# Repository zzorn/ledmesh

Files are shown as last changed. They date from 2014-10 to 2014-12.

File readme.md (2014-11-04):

Ledmesh
=======

Overview
--------

Mesh networked nodes controlling LED light strips, LED spotlights, sensors, and other things.

The network uses wireless radio modules to communicate between nodes.

Ledmesh can be used to create coherent led lighting effects in a space (e.g. light waves flowing around walls), 
as well as for controlling 12V lighting (e.g. led spotlights).

Ledmesh can also be used as an information radiator, connecting some nodes up to computers or suitable sensors, 
and sending out light waves to nearby nodes or doing light effect changes for the whole network on different events.

Ledmesh needs configuration after installation, to tell nodes their relative locations, sensors to use for activating different modes or sending waves, and so on.

Effects
-------

The main type of effect consist of nodes sending waves of light and color along light strips towards neighboring nodes, where the waves can carry on to other nodes.
Waves can have various intensity, hue/sat/lum (also negative), wavelength, travel distance/time, random noise, color gradients, and so on.  Multiple waves can travel along a strip in various directions
at the same time, the different waves are blended together.

Waves could leave the leds at zero after they pass, or they could leave them at some other intensity, which will be changed by the next wave.  (Or the base intensity might be based on the mode(s) the node is in?)

Waves can be used to create a lot of different effects (even global fade ins or outs).  If there are some ideas for effect types that are not possible to do with waves, those might be added later.

Single outputs, like led spotlights, could be treated like a led strip of length one (or some other length, if the spotlights are arranged in a row).

Node States
-----------

Nodes can have various states depending on their sensor readings and global or remote sensor readings received with communication from other nodes.
The state(s) a node is in determines what kind of effects it generates to attached led strips and other outputs.

A node need not be either in a state or not, it can also be partially in a state (e.g. a potentiometer could be used to place a node partially in a 'lit' state).

The degree a state is activated depends either directly or indirectly on one or more sensor inputs, with some multipliers.

Different states can also have different speeds or required activation that they activate or deactivate with (a kind of inertia), to provide some hysteresis and reduce quick flickering between states.

For more complicated behaviour, the activation degree of states in the current or neighboring nodes could be used as a sensor value to help determine the activation of a node (creating a neuron-like setup).

Modes
-----

Sometimes the general apperance of the whole network should be changed.  This could be done with a mode concept, where a mode enables states contained in it, and disables states contained within any previously active mode.
Some states might be independent of the mode.

One possibility is to allow multiple modes as once, although that might be more complications than necessary.

Modes could maybe change depending on signals (which would indicate some hierarchial state system might be better than a separate mode concept).

For example, during the evening a more orange toned lighting mode could be activated, there could be modes for work that needs a lot of light, for more muted lighting for general hanging around,
for some darker and slower night illumination, a party mode, and a few different looking general light modes.

Node types
----------

There are two different types of nodes:

* Led Node
  * Controls zero or more LED strips, LED lights, etc.  Also has two extra I/O pins.
  * Has locations for sensor modules such as PIR (motion detector) and sound.
  * Has builtin light level sensor.
  * Has location for a radio communication module.

* Remote Controller
  * Contains a character LCD screen and turn wheels (and possibly a color / color gradient preview LED) for configuring the network.  It allows:
     * Configuring the length of led strips connected to different nodes (needs to be done once after installation).  
     * Defining fixed signals for different nodes (e.g. height above floor, or x/y coordinate), which can be used in effects.
     * Defining the signals that different inputs on different nodes affect, and whether the signals are global or local to the node.
       Some inputs are pre-configured (e.g. light level sensors, etc), while others could be custom (e.g. door open microswitch, red alert/instant party button, etc).
     * Defining gradients.
     * Defining various named wave types.
     * Defining various wave generators (?).
     * Defining various node states
        * Connecting wave generators to the node state
        * Specifying the activation or deactivation effects of different signals (and state activations) from this node or neighboring nodes or global signals on this state.
        * Default lifetime of this state
        * Slowness / quickness of state change = change inertia
        * Whether this state should be available on all nodes, or only a selected subset (always non-active on other nodes)  [Is this needed?  Maybe not]
     * The default screen allows setting various selected global signals, and selecting the current mode(s).
  * Could also have a USB connection to computer, and some serial based protocol to provide updates to signal states, as well as communicate states from the Ledmess network.  The protocol could also contain commands for configuring LedMesh.
  * Might also contain support for bluetooth control (for control from android app)
  * Might support an ethernet connector as well.

Control and configuration application
-------------------------------------

To be written in Java, as that allows easy porting to both android and PC.

The software on the remote controller will probably be more limited, but it would be nice to be able to do all configuration from it if needed.

Builtin Signals
---------------

* Time of day
* Age of this state (0 = newborn, 100% = at the lifetime of the state).

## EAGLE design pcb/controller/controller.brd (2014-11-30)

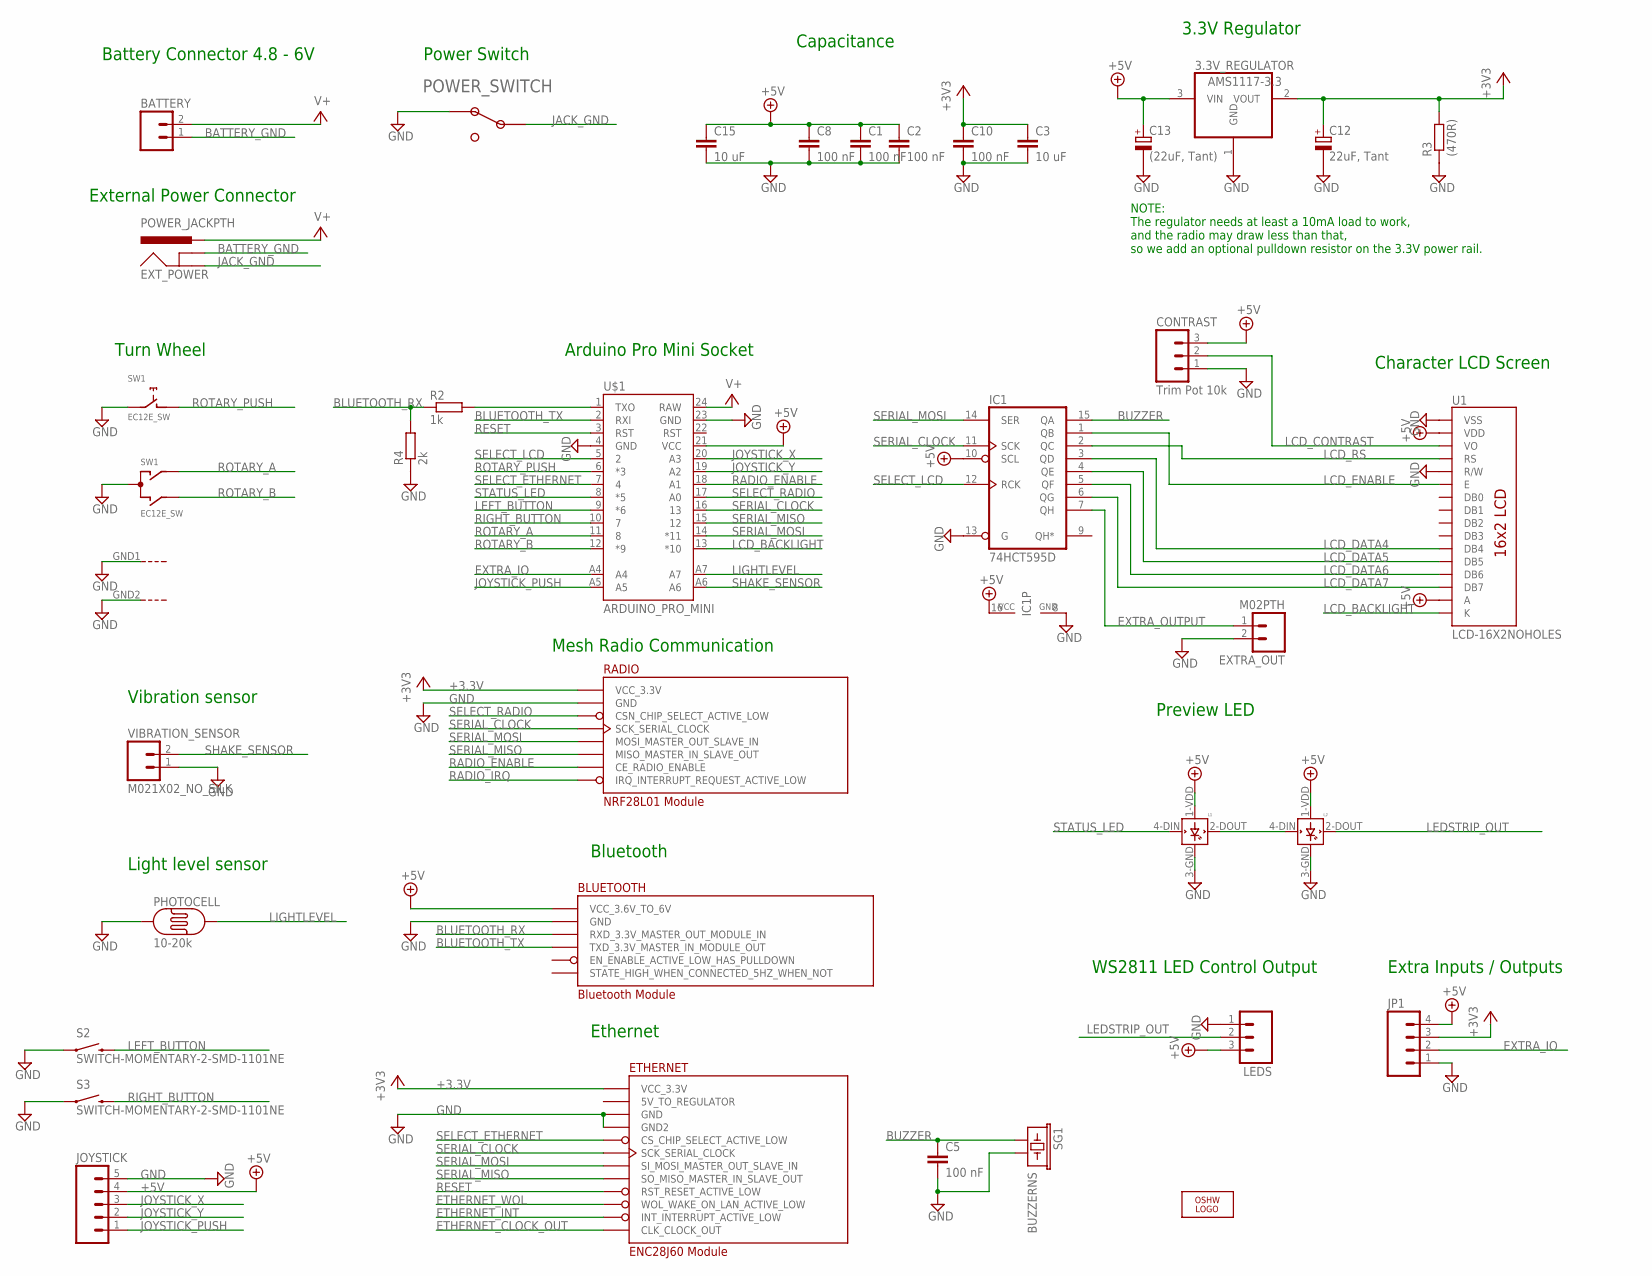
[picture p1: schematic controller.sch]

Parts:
3.3V_REGULATOR: AMS1117-3.3; SOT223
BATTERY: M02LOCK_LONGPADS; 1X02_LOCK_LONGPADS
BLUETOOTH: Bluetooth Module; BLUETOOTH_MODULE
C1, C2, C5, C8, C10: 100 nF; C0805
C3, C15: 10 uF; C0805K
C12: 22uF, Tant; SMC_A
C13: (22uF, Tant); SMC_A
CONTRAST: Trim Pot 10k; 1X03_NO_SILK
ETHERNET: ENC28J60 Module; ETHERNET_ENC28J60_MODULE
EXTRA_OUT: M02PTH; 1X02
EXT_POWER: POWER_JACKPTH; POWER_JACK_PTH
IC1: 74HCT595D; SO16
JOYSTICK: M05NO_SILK; 1X05_NO_SILK
JP1: M041X04_NO_SILK; 1X04_NO_SILK
L1, L2: WS2812B
LEDS: M03PTH; 1X03
LOGO3: LOGO-OSHW-8MILX0100-NT; OSHW_8X100_NOTEXT
PHOTOCELL: 10-20k; PHOTOCELL
POWER_SWITCH: KNC1-101-2P
R2: 1k; M0805
R3: (470R); M0805
R4: 2k; M0805
RADIO: NRF28L01 Module; NRF24L01_MODULE
S2, S3: SWITCH-MOMENTARY-2-SMD-1101NE; TACTILE-SWITCH-1101NE
SG1: BUZZERNS; BUZZER-12MM-NS
SW1: EC12E_SW; ALPS_EC12E_SW
U1: LCD-16X2NOHOLES; LCD-16X2_NOHOLES
U$1: ARDUINO_PRO_MINI
VIBRATION_SENSOR: M021X02_NO_SILK; 1X02_NO_SILK

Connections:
+3.3V: 3.3V_REGULATOR.2 (VOUT), C3.1, C10.1, C12.+, ETHERNET.P$2 (VCC_3.3V), JP1.3, R3.2, RADIO.P$2 (VCC_3.3V)
+5V: 3.3V_REGULATOR.3 (VIN), BLUETOOTH.P$5 (VCC_3.6V_TO_6V), C1.1, C2.1, C8.1, C13.+, C15.1, CONTRAST.3, IC1.10 (SCL), IC1.16 (VCC), JOYSTICK.4, JP1.4, L1.1-VDD (VDD), L2.1-VDD (VDD), LEDS.3, U1.2 (VDD), U1.15 (A), U$1.21 (VCC)
BATTERY_GND: BATTERY.1, EXT_POWER.GNDBREAK
BLUETOOTH_RX: BLUETOOTH.P$2 (RXD_3.3V_MASTER_OUT_MODULE_IN), R2.1, R4.2
BLUETOOTH_TX: BLUETOOTH.P$3 (TXD_3.3V_MASTER_IN_MODULE_OUT), U$1.2 (RXI)
BUZZER: C5.1, IC1.15 (QA), SG1.+ (1)
ETHERNET_CLOCK_OUT: ETHERNET.P$9 (CLK_CLOCK_OUT)
ETHERNET_INT: ETHERNET.P$10 (INT_INTERRUPT_ACTIVE_LOW)
ETHERNET_WOL: ETHERNET.P$7 (WOL_WAKE_ON_LAN_ACTIVE_LOW)
EXTRA_IO: JP1.2, U$1.A4
EXTRA_OUTPUT: EXTRA_OUT.1, IC1.7 (QH)
GND: 3.3V_REGULATOR.1 (GND), BLUETOOTH.P$4 (GND), C1.2, C2.2, C3.2, C5.2, C8.2, C10.2, C12.-, C13.-, C15.2, CONTRAST.1, ETHERNET.P$1 (GND), ETHERNET.P$11 (GND2), EXTRA_OUT.2, IC1.8 (GND), IC1.13 (G), JOYSTICK.5, JP1.1, L1.3-GND (GND), L2.3-GND (GND), LEDS.1, PHOTOCELL.1, POWER_SWITCH.P$1, R3.1, R4.1, RADIO.P$1 (GND), S2.P$1 (1), S3.P$1 (1), SG1.- (2), SW1.C, SW1.E (2), SW1.GND1 (G), SW1.GND2 (G), U1.1 (VSS), U1.5 (R/W), U$1.4 (GND), U$1.23 (GND), VIBRATION_SENSOR.1
JACK_GND: EXT_POWER.GND, POWER_SWITCH.P$2
JOYSTICK_PUSH: JOYSTICK.1, U$1.A5
JOYSTICK_X: JOYSTICK.3, U$1.20 (A3)
JOYSTICK_Y: JOYSTICK.2, U$1.19 (A2)
LCD_BACKLIGHT: U1.16 (K), U$1.13 (*10)
LCD_CONTRAST: CONTRAST.2, U1.3 (VO)
LCD_DATA4: IC1.3 (QD), U1.11 (DB4)
LCD_DATA5: IC1.4 (QE), U1.12 (DB5)
LCD_DATA6: IC1.5 (QF), U1.13 (DB6)
LCD_DATA7: IC1.6 (QG), U1.14 (DB7)
LCD_ENABLE: IC1.1 (QB), U1.6 (E)
LCD_RS: IC1.2 (QC), U1.4 (RS)
LEDSTRIP_OUT: L2.2-DOUT (DOUT), LEDS.2
LEFT_BUTTON: S2.P$2 (2), U$1.9 (*6)
LIGHTLEVEL: PHOTOCELL.2, U$1.A7
unnamed: R2.2, U$1.1 (TXO)
RADIO_ENABLE: RADIO.P$3 (CE_RADIO_ENABLE), U$1.18 (A1)
RADIO_IRQ: RADIO.P$8 (IRQ_INTERRUPT_REQUEST_ACTIVE_LOW)
RESET: ETHERNET.P$4 (RST_RESET_ACTIVE_LOW), U$1.3 (RST)
RIGHT_BUTTON: S3.P$2 (2), U$1.10 (7)
ROTARY_A: SW1.A, U$1.11 (8)
ROTARY_B: SW1.B, U$1.12 (*9)
ROTARY_PUSH: SW1.D (1), U$1.6 (*3)
SELECT_ETHERNET: ETHERNET.P$3 (CS_CHIP_SELECT_ACTIVE_LOW), U$1.7 (4)
SELECT_LCD: IC1.12 (RCK), U$1.5 (2)
SELECT_RADIO: RADIO.P$4 (CSN_CHIP_SELECT_ACTIVE_LOW), U$1.17 (A0)
SERIAL_CLOCK: ETHERNET.P$6 (SCK_SERIAL_CLOCK), IC1.11 (SCK), RADIO.P$5 (SCK_SERIAL_CLOCK), U$1.16 (13)
SERIAL_MISO: ETHERNET.P$8 (SO_MISO_MASTER_IN_SLAVE_OUT), RADIO.P$7 (MISO_MASTER_IN_SLAVE_OUT), U$1.15 (12)
SERIAL_MOSI: ETHERNET.P$5 (SI_MOSI_MASTER_OUT_SLAVE_IN), IC1.14 (SER), RADIO.P$6 (MOSI_MASTER_OUT_SLAVE_IN), U$1.14 (*11)
SHAKE_SENSOR: U$1.A6, VIBRATION_SENSOR.2
STATUS_LED: L1.4-DIN (DIN), U$1.8 (*5)
STATUS_LED2: L1.2-DOUT (DOUT), L2.4-DIN (DIN)
V+: BATTERY.2, EXT_POWER.PWR, U$1.24 (RAW)

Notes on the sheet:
Arduino Pro Mini Socket
Capacitance
Light level sensor
Extra Inputs / Outputs
Battery Connector 4.8 - 6V
Mesh Radio Communication
3.3V Regulator
NOTE: The regulator needs at least a 10mA load to work, and the radio may draw less than that, so we add an optional pulldown resistor on the 3.3V power rail.
Preview LED
Vibration sensor
Turn Wheel
Character LCD Screen
WS2811 LED Control Output
Bluetooth
Ethernet
External Power Connector
Power Switch

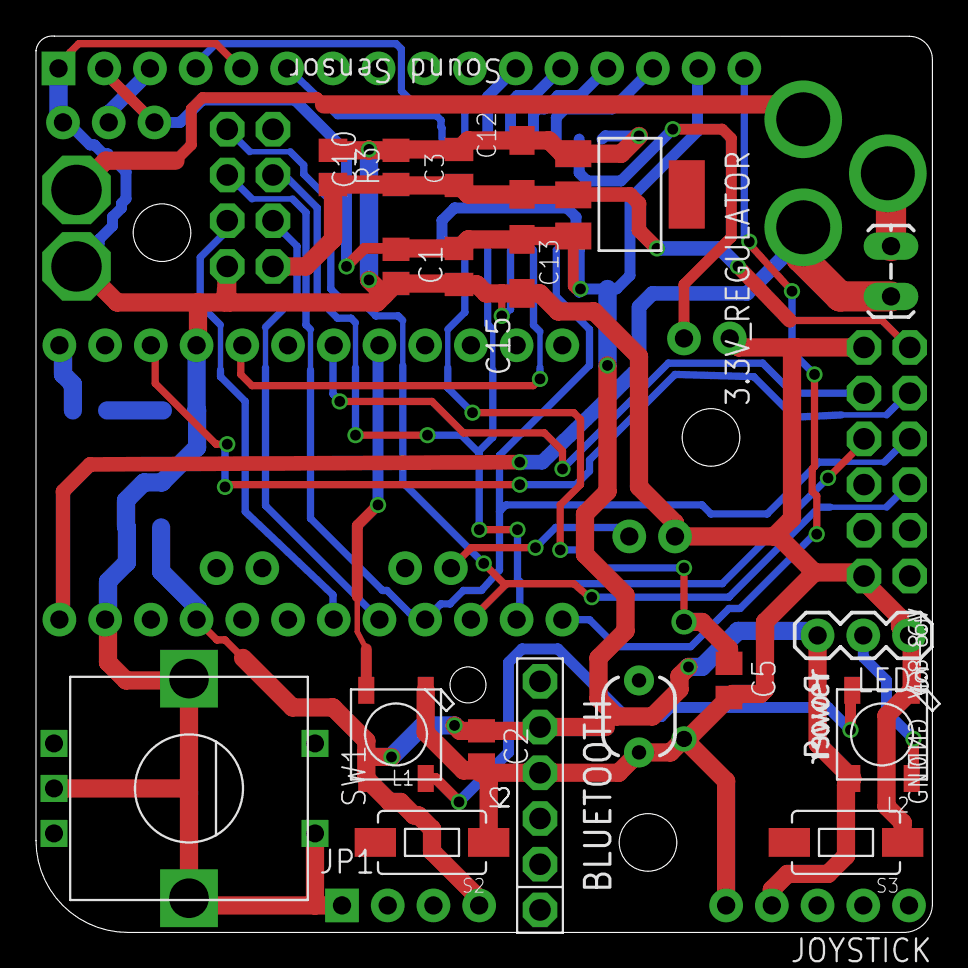
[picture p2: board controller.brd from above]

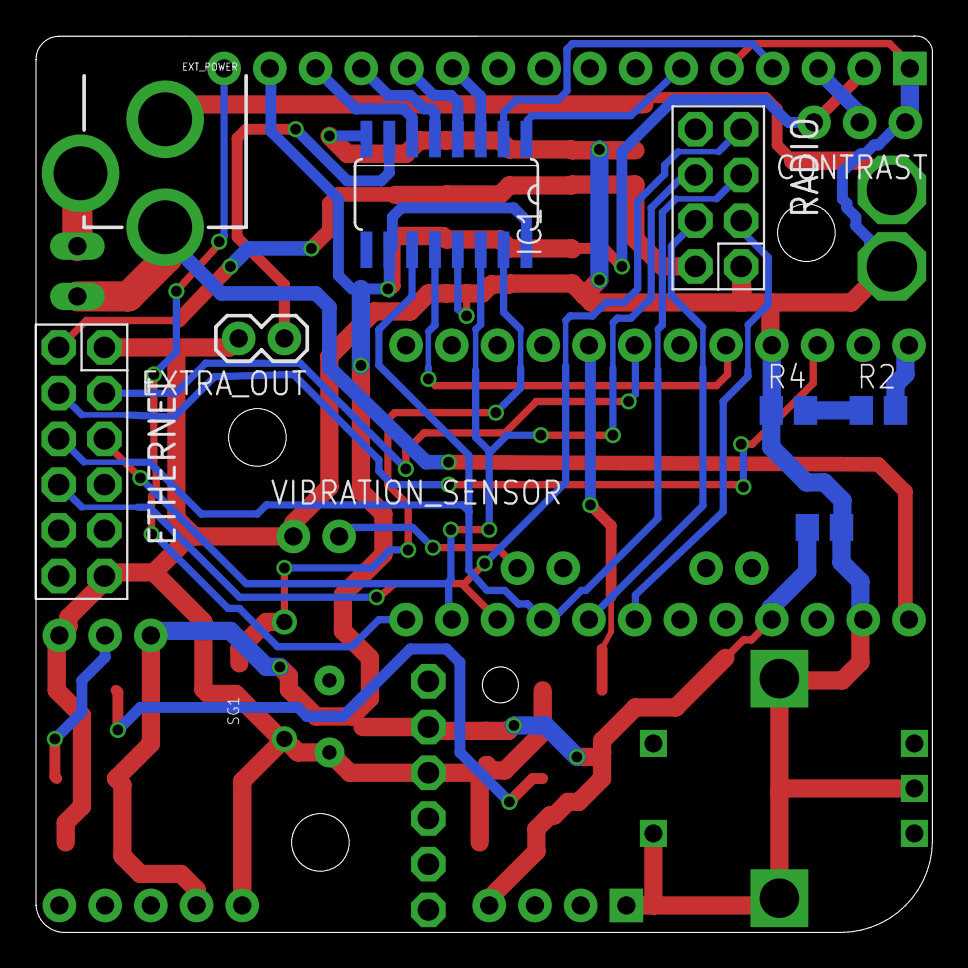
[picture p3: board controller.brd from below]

Board: 2 copper layers, 49.8 x 49.8 mm, 36 parts (12 on the bottom side), 41 nets.

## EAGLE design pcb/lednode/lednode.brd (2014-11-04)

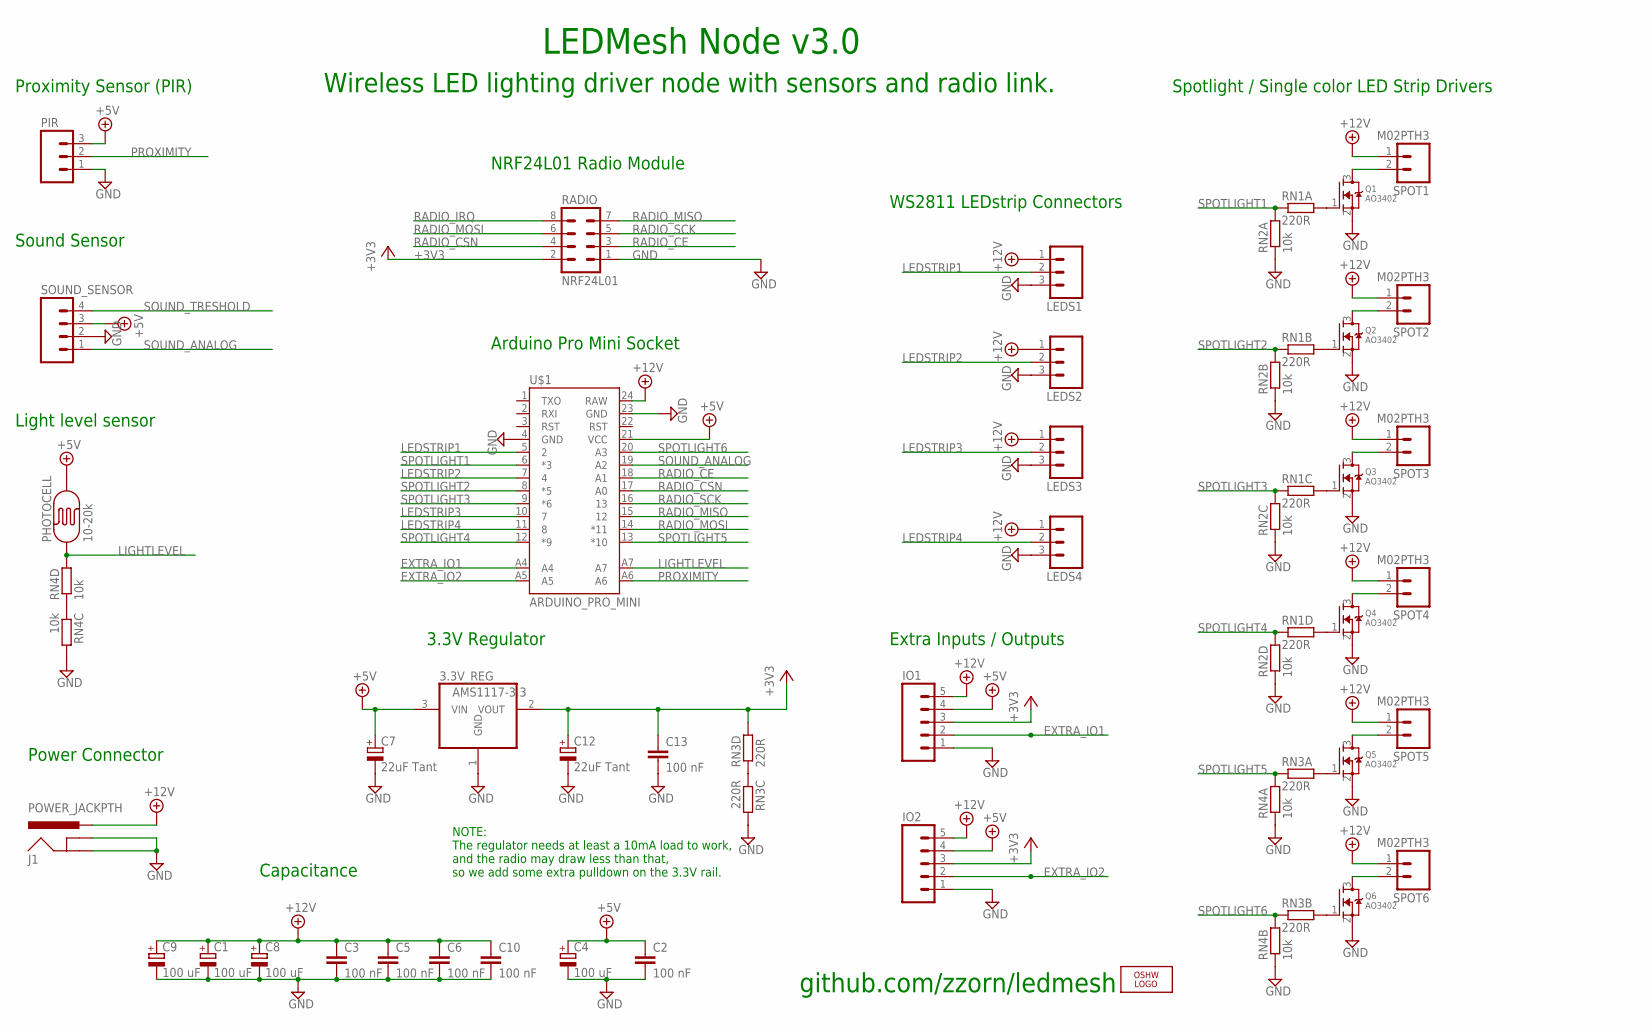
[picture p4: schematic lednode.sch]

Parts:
3.3V_REG: AMS1117-3.3; SOT223
C1, C4, C8, C9: 100 uF; E2,5-6
C2, C3, C5, C6, C10, C13: 100 nF; C0805
C7, C12: 22uF Tant; SMC_A
IO1, IO2: M05PTH; 1X05
J1: POWER_JACKPTH; POWER_JACK_PTH
LEDS1, LEDS2, LEDS3, LEDS4: M03LONGPADS; 1X03_LONGPADS
LOGO3: LOGO-OSHW-8MILX0100-NT; OSHW_8X100_NOTEXT
PHOTOCELL: 10-20k; PHOTOCELL
PIR: M03PTH; 1X03
Q1, Q2, Q3, Q4, Q5, Q6: AO3402; SOT23-W
RADIO: NRF24L01; MA04-2
RN1, RN3: 220R; RN8P-4R-CRA06S
RN2, RN4: 10k; RN8P-4R-CRA06S
SOUND_SENSOR: M041X04_NO_SILK; 1X04_NO_SILK
SPOT1, SPOT2, SPOT3, SPOT4, SPOT5, SPOT6: M02PTH3; 1X02_LONGPADS
U$1: ARDUINO_PRO_MINI

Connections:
+3V3: 3.3V_REG.2 (VOUT), C12.+, C13.1, IO1.3, IO2.3, RADIO.2, RN3.5 (2)
+5V: 3.3V_REG.3 (VIN), C2.1, C4.+, C7.+, IO1.4, IO2.4, PHOTOCELL.2, PIR.3, SOUND_SENSOR.3, U$1.21 (VCC)
+12V: C1.+, C3.1, C5.1, C6.1, C8.+, C9.+, C10.1, IO1.5, IO2.5, J1.PWR, LEDS1.1, LEDS2.1, LEDS3.1, LEDS4.1, SPOT1.1, SPOT2.1, SPOT3.1, SPOT4.1, SPOT5.1, SPOT6.1, U$1.24 (RAW)
EXTRA_IO1: IO1.2, U$1.A4
EXTRA_IO2: IO2.2, U$1.A5
GND: 3.3V_REG.1 (GND), C1.-, C2.2, C3.2, C4.-, C5.2, C6.2, C7.-, C8.-, C9.-, C10.2, C12.-, C13.2, IO1.1, IO2.1, J1.GND, J1.GNDBREAK, LEDS1.3, LEDS2.3, LEDS3.3, LEDS4.3, PIR.1, Q1.2 (S), Q2.2 (S), Q3.2 (S), Q4.2 (S), Q5.2 (S), Q6.2 (S), RADIO.1, RN2.1, RN2.2 (1), RN2.3 (1), RN2.4 (1), RN3.6 (2), RN4.1, RN4.2 (1), RN4.6 (2), SOUND_SENSOR.2, U$1.4 (GND), U$1.23 (GND)
LEDSTRIP1: LEDS1.2, U$1.5 (2)
LEDSTRIP2: LEDS2.2, U$1.7 (4)
LEDSTRIP3: LEDS3.2, U$1.10 (7)
LEDSTRIP4: LEDS4.2, U$1.11 (8)
LIGHTLEVEL: PHOTOCELL.1, RN4.5 (2), U$1.A7
unnamed: Q5.3 (D), SPOT5.2
unnamed: Q1.3 (D), SPOT1.2
unnamed: Q2.3 (D), SPOT2.2
unnamed: Q4.3 (D), SPOT4.2
unnamed: Q3.3 (D), SPOT3.2
unnamed: Q1.1 (G), RN1.8 (2)
unnamed: Q2.1 (G), RN1.7 (2)
unnamed: Q4.1 (G), RN1.5 (2)
unnamed: Q3.1 (G), RN1.6 (2)
unnamed: Q5.1 (G), RN3.8 (2)
unnamed: Q6.3 (D), SPOT6.2
unnamed: RN4.3 (1), RN4.4 (1)
unnamed: Q6.1 (G), RN3.7 (2)
unnamed: RN3.3 (1), RN3.4 (1)
PROXIMITY: PIR.2, U$1.A6
RADIO_CE: RADIO.3, U$1.18 (A1)
RADIO_CSN: RADIO.4, U$1.17 (A0)
RADIO_IRQ: RADIO.8
RADIO_MISO: RADIO.7, U$1.15 (12)
RADIO_MOSI: RADIO.6, U$1.14 (*11)
RADIO_SCK: RADIO.5, U$1.16 (13)
SOUND_ANALOG: SOUND_SENSOR.1, U$1.19 (A2)
SOUND_TRESHOLD: SOUND_SENSOR.4
SPOTLIGHT1: RN1.1, RN2.8 (2), U$1.6 (*3)
SPOTLIGHT2: RN1.2 (1), RN2.7 (2), U$1.8 (*5)
SPOTLIGHT3: RN1.3 (1), RN2.6 (2), U$1.9 (*6)
SPOTLIGHT4: RN1.4 (1), RN2.5 (2), U$1.12 (*9)
SPOTLIGHT5: RN3.1, RN4.8 (2), U$1.13 (*10)
SPOTLIGHT6: RN3.2 (1), RN4.7 (2), U$1.20 (A3)

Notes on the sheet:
Arduino Pro Mini Socket
Capacitance
WS2811 LEDstrip Connectors
Light level sensor
Proximity Sensor (PIR)
Extra Inputs / Outputs
Power Connector
Spotlight / Single color LED Strip Drivers
Sound Sensor
NRF24L01 Radio Module
3.3V Regulator
NOTE: The regulator needs at least a 10mA load to work, and the radio may draw less than that, so we add some extra pulldown on the 3.3V rail.
LEDMesh Node v3.0
Wireless LED lighting driver node with sensors and radio link.
github.com/zzorn/ledmesh

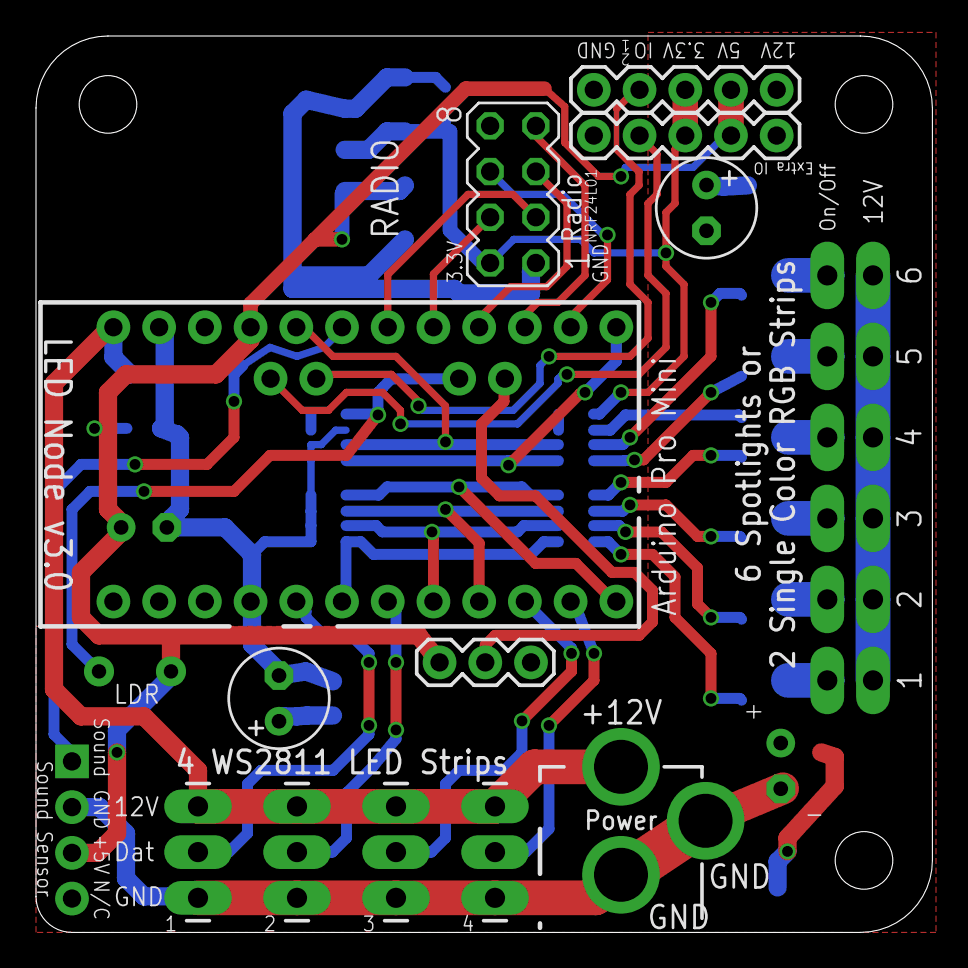
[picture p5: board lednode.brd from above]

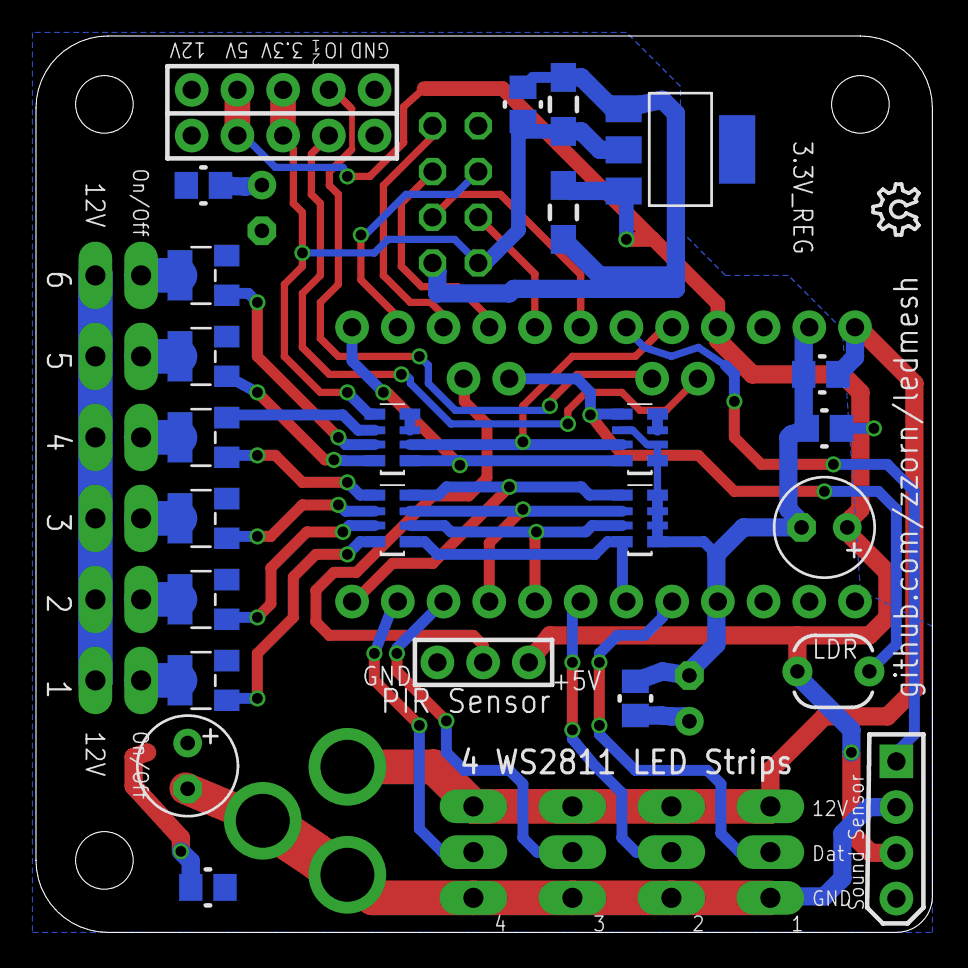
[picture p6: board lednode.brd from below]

Board: 2 copper layers, 49.8 x 49.8 mm, 42 parts (23 on the bottom side), 38 nets.

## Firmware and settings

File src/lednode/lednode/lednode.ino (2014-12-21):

#include <RHDatagram.h>
#include <RH_NRF24.h>
#include <SPI.h>

#include "FastLED.h"


// Pins
#define PIN_LEDSTRIP1 2
#define PIN_LEDSTRIP2 4
#define PIN_LEDSTRIP3 7
#define PIN_LEDSTRIP4 8

#define PIN_SPOTLIGHT1 3
#define PIN_SPOTLIGHT2 5
#define PIN_SPOTLIGHT3 6
#define PIN_SPOTLIGHT4 9
#define PIN_SPOTLIGHT5 10
#define PIN_SPOTLIGHT6 A3

#define PIN_RADIO_ENABLE A1
#define PIN_RADIO_CSN A0
#define PIN_RADIO_CLOCK 13
#define PIN_RADIO_MISO 12
#define PIN_RADIO_MOSI 11

#define PIN_SOUND_ANALOG A2
#define PIN_LIGHTLEVEL A7
#define PIN_PROXIMITY A6

#define PIN_EXTRAIO1 A4
#define PIN_EXTRAIO2 A5

#define LEDSTRIP_COUNT 4

int ledstripPins[] = {
  PIN_LEDSTRIP1,
  PIN_LEDSTRIP2,
  PIN_LEDSTRIP3,
  PIN_LEDSTRIP4
};

#define SPOTLIGHT_COUNT 6

int spotlightPins[] = {
  PIN_SPOTLIGHT1,
  PIN_SPOTLIGHT2,
  PIN_SPOTLIGHT3,
  PIN_SPOTLIGHT4,
  PIN_SPOTLIGHT5,
  PIN_SPOTLIGHT6
};


// Address of this node
// TODO: This needs to be incrementally defined for each node when programming them?  Or look for a free address and save / load it from eprom
#define DEFAULT_NODE_ADDRESS 99
uint8_t thisNodeAddress = DEFAULT_NODE_ADDRESS;

// Singleton instance of the radio driver
RH_NRF24 driver(PIN_RADIO_ENABLE, PIN_RADIO_CSN);

// Class to manage message delivery and receipt, using the driver declared above
RHDatagram manager(driver, thisNodeAddress);


void printMessage(char* message) {
  Serial.println(message);
//  Serial.flush();
}

void printValue(char* message, int value) {
  Serial.print(message);
  Serial.println(value, DEC);
//  Serial.flush();
}


// Array with current led colors
#define MAX_LED_COUNT 150
#define DEFAULT_LED_COUNT 20
CRGB ledColors[MAX_LED_COUNT];
byte ledAlpha[MAX_LED_COUNT];

short nextFreeLed = 0;

//--------------------------------------------------------
// Holds data for one led strip
class LedStrip {
  
  short ledCount;
  short startLed;  

  public:
  void init(byte pin_, byte ledCount_) {
    
    startLed = nextFreeLed;
    
    int numAvailable = MAX_LED_COUNT - nextFreeLed;
    if (numAvailable <= 0) {
      // No free leds left
      ledCount = 0;
    }
    else if (numAvailable < ledCount_) {
      // Not enough free leds left
      ledCount = numAvailable;
    }
    else {    
      ledCount = ledCount_;
    }
    
    nextFreeLed += ledCount;

    printValue("pin ", pin_);
    printValue("startLed ", startLed);
    printValue("ledCount ", ledCount);
    printValue("nextFeeLed ", nextFreeLed);
    
    // Register with fastled library
    if (ledCount > 0) {    
      CRGB* colors = &ledColors[nextFreeLed];

      // Kludge to manage pins that need to be passed in as constants
      switch(pin_) {
        case PIN_LEDSTRIP1: FastLED.addLeds<NEOPIXEL, PIN_LEDSTRIP1>(colors, ledCount); break;
        case PIN_LEDSTRIP2: FastLED.addLeds<NEOPIXEL, PIN_LEDSTRIP2>(colors, ledCount); break;
        case PIN_LEDSTRIP3: FastLED.addLeds<NEOPIXEL, PIN_LEDSTRIP3>(colors, ledCount); break;
        case PIN_LEDSTRIP4: FastLED.addLeds<NEOPIXEL, PIN_LEDSTRIP4>(colors, ledCount); break;
        default: printValue("Unsupported led strip pin ", pin_); break;
      }
    }
  }  
  
};

LedStrip ledStrips[LEDSTRIP_COUNT];

//--------------------------------------------------------
// Handles a wave that moves along a ledstrip and updates led colors
class Wave {
  LedStrip* ledStrip;

  short pos;
  byte length;

  // Movement speed (negative to left, positive to right)
  short speed_millisecondsPerLed;
  
  
  // TODO Continud here


};







//--------------------------------------------------------

CRGB currentColor;
CRGB targetColor;

#define MODE_OFF 0x00
#define MODE_LIGHT 0x01
#define MODE_COLOR 0x02
#define MODE_WAVES 0x03
#define MODE_SPARKLE 0x04

uint8_t targetMode = MODE_LIGHT;

CRGB LIGHT_COLOR = CRGB(255, 70, 170);


// Dont put this on the stack:
uint8_t buffer[RH_NRF24_MAX_MESSAGE_LEN];


#define MESSAGE_SET_COLOR 0x02
#define MESSAGE_SET_MODE 0x03

long scrollSpeed_ms_per_step = 20;

boolean enableParticles = false;

unsigned long currentTime_ms = 0;
long ledCoolDown_ms = 0;


CRGB randomColor() {
   CRGB c;
   c.r = random8();   
   c.g = random8();   
   c.b = random8();   
   return c;
}


void setup()  {
  Serial.begin(9600);

  Serial.println("Initializing");
  printMessage("Lednode starting up...");

  // Setup pins
  printMessage("Setting up pins");
  for (int i = 0; i < LEDSTRIP_COUNT; i++) {
     pinMode(ledstripPins[i], OUTPUT);
  }
  for (int i = 0; i < SPOTLIGHT_COUNT; i++) {
     pinMode(spotlightPins[i], OUTPUT);
  }
  pinMode(PIN_RADIO_ENABLE, OUTPUT);
  pinMode(PIN_RADIO_CSN, OUTPUT);
  pinMode(PIN_RADIO_CLOCK, OUTPUT);
  pinMode(PIN_RADIO_MOSI, OUTPUT);
  pinMode(PIN_RADIO_MISO, INPUT);

  pinMode(PIN_SOUND_ANALOG, INPUT);
  pinMode(PIN_LIGHTLEVEL, INPUT);
  pinMode(PIN_PROXIMITY, INPUT);

  pinMode(PIN_EXTRAIO1, INPUT);
  pinMode(PIN_EXTRAIO2, INPUT);

  // Setup ledstrips
  Serial.println("Setting up ledstrips");
/*
  for (int i = 0; i < LEDSTRIP_COUNT; i++) {
      ledStrips[i].init(ledstripPins[i], DEFAULT_LED_COUNT);
  }
  */
  ledStrips[0].init(ledstripPins[0], 50);

/*
  // Init radio  
  printMessage("Setting up radio");
  if (!manager.init()) {
    Serial.println("Radio init failed");
  }  
  // Defaults after init are 2.402 GHz (channel 2), 2Mbps, 0dBm

    
*/
  targetColor = CRGB::Red;
  currentColor = randomColor();   

  printMessage("Lednode started.");
  
  
  // DEBUG
  analogWrite(PIN_SPOTLIGHT1, 255);
  analogWrite(PIN_SPOTLIGHT2, 140);
  analogWrite(PIN_SPOTLIGHT3, 10);
  digitalWrite(PIN_SPOTLIGHT4, HIGH);
  digitalWrite(PIN_SPOTLIGHT5, HIGH);
  digitalWrite(PIN_SPOTLIGHT6, HIGH);
}



boolean checkParametrs(uint8_t command, uint8_t len, uint8_t requiredParamLength) {
  if (len < 1 + requiredParamLength) { 
    Serial.print("Too few parameters passed for message type ");    
    Serial.println(command, HEX);    
    Serial.print("Required ");    
    Serial.print(requiredParamLength);    
    Serial.print(" bytes, but got ");    
    Serial.print(len - 1);    
    Serial.println(" bytes.");    
    return false;
  }
  else {
    return true;
  }
}

void debugMessage(char* errorMessage, uint8_t messageType, uint8_t parameters[], int paramLength) {
    Serial.print(errorMessage);
    Serial.print(".  Message Type ");
    Serial.print(messageType, HEX);       
    Serial.print(", parameters: ");
    for (int i = 0; i < paramLength; i++) {
      Serial.print(parameters[i], HEX);       
      Serial.print(" ");       
    }
    Serial.print(" ( parameter length ");
    Serial.print(paramLength);
    Serial.println(" bytes)");

} 


void handleMessage(uint8_t buffer[], uint8_t length) {
  if (length < 1) {
    Serial.print("Received empty message.");    
    return;
  }
  
  uint8_t messageType = buffer[0];
  uint8_t *params = &buffer[1];

  debugMessage("Received message", messageType, params, length - 1);  
  
  switch (messageType) {
    case MESSAGE_SET_COLOR:
      if (!checkParametrs(messageType, length, 3)) return;
      targetColor.r = params[0];
      targetColor.g = params[1];
      targetColor.b = params[2];   
      currentColor = targetColor;   
      break;
    
    case MESSAGE_SET_MODE:
      if (!checkParametrs(messageType, length, 1)) return;
      targetMode = params[0];
      Serial.print("Mode changed to ");    
      Serial.println(targetMode);    

      break;
    
    default:
      debugMessage("Unknown message type", messageType, params, length - 1);  
      break;
  }
   
}


void updateRadio(long deltaTime_ms) {
  // Check if a message is available for us
  if (manager.available()) {
    uint8_t len = sizeof(buffer);
    uint8_t from;
    if (manager.recvfrom(buffer, &len, &from)) {  
       handleMessage(buffer, len);      
    }
  }  
}


/**
 * t = from 0 (returns a) to 1024 (returns b).
 */
int mix(int32_t a, int32_t b, int32_t t) {
  return a + ((b - a) * t) >> 10;
}

/**
 * Interpolates between two colors.  
 * amount is from 0 (100% from color) to 1024 (100% to color).
 */
CRGB mixColor(CRGB from, CRGB to, int amount) {

  // Interpolate components 
  int r = mix(from.r, to.r, amount);
  int g = mix(from.g, to.g, amount);
  int b = mix(from.b, to.b, amount);

  // Clamp  
  if (r < 0) r = 0;
  else if (r > 255) r = 255;

  if (g < 0) g = 0;
  else if (g > 255) g = 255;

  if (b < 0) b = 0;
  else if (b > 255) b = 255;

  // Create color and return it
  return CRGB(r, g, b);  
}

void updateSolidColorMode(long deltaTime_ms, CRGB color) {

    // Set to target  
    int mixAmount = 200;
    for (int i = 0; i < MAX_LED_COUNT; i++) {
        ledColors[i] = color;
    }

}



long waveSpeed = 16;
long wavePos = 0;
void updateWaveMode(long deltaTime_ms) {
    // Calculate source colors
    wavePos += deltaTime_ms * waveSpeed;
    if (wavePos > 32767) wavePos -= 32767;
    int pos = sin16(wavePos * waveSpeed) / (65535 / 512) + 512;
    CRGB sourceColor1 = mixColor(targetColor, CRGB::Black, pos);
    CRGB sourceColor2 = mixColor(targetColor, CRGB::Black, 1024 - pos);
  
    // Bleed color down the line  
    int bleedAmount = 300;
    for (int i = MAX_LED_COUNT - 1; i > 0; i--) {
        ledColors[i] += mixColor(ledColors[i], ledColors[i - 1], bleedAmount);
    }
    
    // Bleed current color to first ones
    ledColors[0] = mixColor(ledColors[0], sourceColor1, bleedAmount);

    // Dampen colors
    for (int i = 0; i < MAX_LED_COUNT; i++) {
        ledColors[i].fadeToBlackBy(1);
    }
}


long sparkleIntervall_ms = 200;
long timeToNextSparkle = 1;
CRGB GRADIENT_FIRE_COLORS[] = {CRGB(255, 240, 150), CRGB(220, 180, 0), CRGB(200, 0, 0), CRGB(30, 0, 50), CRGB(0, 0, 60), CRGB(0, 0, 0)};
long GRADIENT_FIRE_DURATIONS[] = {500, 1000, 500, 2000, 100, 3000};


void updateLeds(long deltaTime_ms) {
  // Check if it is time to update the leds yet 
  ledCoolDown_ms -= deltaTime_ms;
  if (ledCoolDown_ms <= 0) { 
    ledCoolDown_ms += scrollSpeed_ms_per_step;

    switch (targetMode) {
      case MODE_OFF:
        enableParticles = false;
        updateSolidColorMode(ledCoolDown_ms, CRGB::Black);
        break;
        
      case MODE_LIGHT:
        enableParticles = false;
        updateSolidColorMode(ledCoolDown_ms, LIGHT_COLOR);
        break;
        
      case MODE_COLOR:
        enableParticles = false;
        updateSolidColorMode(ledCoolDown_ms, targetColor);
        break;
        
      case MODE_WAVES:
        enableParticles = true;
        updateWaveMode(ledCoolDown_ms);
        break;
        
      default:
        // Unknown mode
        updateSolidColorMode(ledCoolDown_ms, CRGB::Red);
        break;      
    }

    // Show the updated led colors
    FastLED.show();

  }  
}




/**
 * Returns the number of milliseconds since the last call to this method.
 * Also updates the currentTime_ms variable to be the number of milliseconds since the start of the program, or the last timer wraparound (happens every 50 days or so).
 */
long calculateDeltaTime() {
  unsigned long now = millis();
  long deltaTime_ms;

  // Handle startup and millis() wraparound (happends every 50 days or so)
  if (currentTime_ms == 0 || now < currentTime_ms) {
    deltaTime_ms = 0;
  } 
  else {
    // Calculate number of milliseconds since the last call to this method
    deltaTime_ms = now - currentTime_ms;
  }
  
  // Update current time;
  currentTime_ms = now;
  
  // Return delta
  return deltaTime_ms;
}



/**
 * Main loop.
 */
void loop() {

  // Determine time step
  long deltaTime_ms = calculateDeltaTime();
    
  // Update subsystems
  //updateRadio(deltaTime_ms);  
  updateLeds(deltaTime_ms);  

//  Serial.println("ping");
  
//  delay(500);


}

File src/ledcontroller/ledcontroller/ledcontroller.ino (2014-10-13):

#include <RHDatagram.h>
#include <RH_NRF24.h>
#include <SPI.h>
#include <LiquidCrystal.h>
#include <FastLED.h>
 

#include "FastLED.h"

// Test addresses
#define CLIENT_ADDRESS 1
#define SERVER_ADDRESS 2

// Prints extra many things
#define DEBUG_MODE true

// Pin assignments
#define LCD_RS_PIN        2
#define LCD_ENABLE_PIN    3
#define LCD_DATA4_PIN     4
#define LCD_DATA5_PIN     5
#define LCD_DATA6_PIN     6
#define LCD_DATA7_PIN     7
#define ROTARY_A_PIN      8 
#define ROTARY_B_PIN      9
#define LCD_BACKLIGHT_PIN 10
#define RADIO_MOSI_PIN    11
#define RADIO_MISO_PIN    12
#define RADIO_SCK_PIN     13    
#define RADIO_CSN_PIN     A0
#define RADIO_CE_PIN      A1 
#define ROTARY_PUSH_PIN   A2
#define STATUS_LED_PIN    A3
#define EXTRA_IO_1_PIN    A4
#define EXTRA_IO_2_PIN    A5
#define SHAKE_PIN         A6
#define LIGHTLEVEL_PIN    A7



// LCD library
LiquidCrystal lcd(LCD_RS_PIN, LCD_ENABLE_PIN, LCD_DATA4_PIN, LCD_DATA5_PIN, LCD_DATA6_PIN, LCD_DATA7_PIN);

// Singleton instance of the radio driver
RH_NRF24 driver(RADIO_CE_PIN, RADIO_CSN_PIN);

// Class to manage message delivery and receipt, using the driver declared above
RHDatagram manager(driver, SERVER_ADDRESS);

// Dont put this on the stack:
uint8_t buffer[RH_NRF24_MAX_MESSAGE_LEN];


#define MESSAGE_SET_COLOR 0x02
#define MESSAGE_SET_MODE 0x03

#define MODE_OFF 0x00
#define MODE_LIGHT 0x01
#define MODE_COLOR 0x02
#define MODE_WAVES 0x03
#define MODE_SPARKLE 0x04
#define FIRST_MODE MODE_OFF
#define LAST_MODE MODE_SPARKLE
const int NUM_MODES = LAST_MODE + 1;

char* MODE_NAMES[NUM_MODES] = {
  "Off",
  "Light",
  "Color",
  "Waves",
  "Sparkle",
};

#define NUM_LEDS 1
CRGB previewLeds[NUM_LEDS];

CRGB targetColor;
int currentHue = 0;
int currentMode = FIRST_MODE;


unsigned long currentTime_ms = 0;


CRGB randomColor() {
   CRGB c;
   c.r = random8();   
   c.g = random8();   
   c.b = random8();   
   return c;
}


void setup() {
   /*
   pinMode(LCD_RS_PIN, OUTPUT);
   pinMode(LCD_ENABLE_PIN, OUTPUT);
   pinMode(LCD_DATA4_PIN, OUTPUT);
   pinMode(LCD_DATA5_PIN, OUTPUT);
   pinMode(LCD_DATA6_PIN, OUTPUT);
   pinMode(LCD_DATA7_PIN, OUTPUT);
   */
   pinMode(LCD_BACKLIGHT_PIN, OUTPUT);

   pinMode(STATUS_LED_PIN, OUTPUT);

   pinMode(EXTRA_IO_1_PIN, INPUT);
   pinMode(EXTRA_IO_2_PIN, INPUT);

   pinMode(ROTARY_A_PIN, INPUT);  
   pinMode(ROTARY_B_PIN, INPUT);  
   pinMode(ROTARY_PUSH_PIN, INPUT);

   pinMode(SHAKE_PIN, INPUT);
   pinMode(LIGHTLEVEL_PIN, INPUT);  


  Serial.begin(9600);

  lcd.begin(16, 2);
  lcd.print("Light Controller");

  FastLED.addLeds<NEOPIXEL, STATUS_LED_PIN>(previewLeds, NUM_LEDS);

  // Defaults after init are 2.402 GHz (channel 2), 2Mbps, 0dBm
  if (!manager.init()) {
    Serial.println("Radio initialization failed");
    lcd.print("Radio init fail");    
  }
    
  targetColor = randomColor(); 

  analogWrite(LCD_BACKLIGHT_PIN, 0);

 
}



boolean checkParametrs(uint8_t command, uint8_t len, uint8_t requiredParamLength) {
  if (len < 1 + requiredParamLength) { 
    Serial.print("Too few parameters passed for message type ");    
    Serial.println(command, HEX);    
    Serial.print("Required ");    
    Serial.print(requiredParamLength);    
    Serial.print(" bytes, but got ");    
    Serial.print(len - 1);    
    Serial.println(" bytes.");    
    return false;
  }
  else {
    return true;
  }
}

void handleMessage(uint8_t buffer[], uint8_t length) {
  Serial.print("Got message: ");
  Serial.println((char*)buffer);  
  
  if (length < 1) {
    Serial.print("Empty message.");    
    return;
  }
  
  uint8_t messageType = buffer[0];

  switch (messageType) {
    
    default:
      Serial.print("Unknown message type: ");    
      Serial.println(messageType, HEX);
      break;
  }
   
}


void updateRadio(long deltaTime_ms) {
  // Check if a message is available for us
  if (manager.available()) {
    uint8_t len = sizeof(buffer);
    uint8_t from;
    if (manager.recvfrom(buffer, &len, &from)) {  
       handleMessage(buffer, len);      
    }
  } 
}


/**
 * t = from 0 (returns a) to 1024 (returns b).
 */
int mix(int32_t a, int32_t b, int32_t t) {
  return a + ((b - a) * t) >> 10;
}

/**
 * Interpolates between two colors.  
 * amount is from 0 (100% from color) to 1024 (100% to color).
 */
CRGB mixColor(CRGB from, CRGB to, int amount) {

  // Interpolate components 
  int r = mix(from.r, to.r, amount);
  int g = mix(from.g, to.g, amount);
  int b = mix(from.b, to.b, amount);

  // Clamp  
  if (r < 0) r = 0;
  else if (r > 255) r = 255;

  if (g < 0) g = 0;
  else if (g > 255) g = 255;

  if (b < 0) b = 0;
  else if (b > 255) b = 255;

  // Create color and return it
  return CRGB(r, g, b);  
}


void debugMessage(char* errorMessage, uint8_t messageType, uint8_t parameters[], int paramLength) {
    Serial.print(errorMessage);
    Serial.print(".  Message Type ");
    Serial.print(messageType, HEX);       
    Serial.print(", parameters: ");
    for (int i = 0; i < paramLength; i++) {
      Serial.print(parameters[i], HEX);       
      Serial.print(" ");       
    }
    Serial.print(" ( parameter length ");
    Serial.print(paramLength);
    Serial.println(" bytes)");

} 

// TODO: Take variable number of arguments of type unsigned byte, create parameter array in this method.
void sendMessage(uint8_t recipient, uint8_t messageType, uint8_t parameters[], int paramLength) {
  if (paramLength + 1 > sizeof(buffer)) {
    debugMessage("Not enough buffer space to send message", messageType, parameters, paramLength);
    return;
  }

  // Copy to buffer
  buffer[0] = messageType;
  for (int i = 0; i < paramLength; i++) {
    buffer[i + 1] = parameters[i];
  }

  // Send  
  if (!manager.sendto(buffer, paramLength + 1, recipient)) {
    debugMessage("Message too long for the driver to send", messageType, parameters, paramLength);
    return;
  }

  // Print if in debug mode
  if (DEBUG_MODE) {
    debugMessage("Sending message", messageType, parameters, paramLength);
  }
}
  



void sendSetColor(CRGB color) {
  uint8_t rgb[3];
  rgb[0] = color.r;
  rgb[1] = color.b; // TODO: Temporary fix, it seems the lednode mixes blue and green?
  rgb[2] = color.g;
  
  sendMessage(RH_BROADCAST_ADDRESS, MESSAGE_SET_COLOR, rgb, 3);  
}

void sendChangeMode(int currentMode) {
  uint8_t mode[1];
  mode[0] = currentMode;
  
  sendMessage(RH_BROADCAST_ADDRESS, MESSAGE_SET_MODE, mode, 1);  
}

void previewColor(CRGB color) {
  // Send the color to the WS2812B led on pin STATUS_LED_PIN.
  previewLeds[0] = color; 
  FastLED.show(); 
}

void refreshLcd() {
  lcd.clear();
  lcd.setCursor(0, 0);
  lcd.print(MODE_NAMES[currentMode]);
  lcd.setCursor(0, 1);
  lcd.print("Hue = ");  
  lcd.print(currentHue);  
}


void setMode(int mode) {
  currentMode = mode;  
  previewColor(CRGB::Black);
  refreshLcd();
  sendChangeMode(currentMode); 
}
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

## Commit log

2010-12-21 Added used library to drive the LED PWM IC (TLC5940).
2014-09-13 Reused old project for new mesh networked led lightning project. Fleshed out general design plan in the readme document.
2014-09-15 Lednode schema mostly done. Powernode still needs work.
    [lednode.brd, lednode.sch, powernode.brd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]
2014-09-19 Finetned lednode schema, laid out components on lednode board, started routing.
    [lednode.brd, lednode.sch]
2014-09-20 Layout and routing done, silkscreens mostly done.
    [lednode.brd, lednode.sch]
2014-09-22 Final touches.
    [lednode.brd, lednode.sch]
2014-09-22 Final cleanup and gerber generation.
    [lednode.brd, lednode.sch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]
2014-09-23 Started working on powernode. Separated controlnode into an own module.
    [controlnode.brd, controlnode.sch]
2014-09-23 working on powernode.
    [powernode.brd, powernode.sch]
2014-09-25 Working on powernone.
    [powernode.brd, powernode.sch]
2014-09-26 Working on power / control node.
    [powernode.brd, powernode.sch]
2014-09-27 Work on powernode.
    [powernode.brd, powernode.sch]
2014-09-29 Working on powernode layout.
    [powernode.brd, powernode.sch]
2014-10-01 Started working on version two of the led node, based on wireless communication.
    [lednode2.brd, lednode2.sch]
2014-10-01 Working on new node version.
    [lednode2.brd, lednode2.sch]
2014-10-02 Working on lednode v2.0
    [lednode2.brd, lednode2.sch]
2014-10-03 Started working on ledcontroller software for the embedded arduinos.
2014-10-10 Started working on (remote) controller.
    [controller.brd, controller.sch]
2014-10-17 Simplified controller design, internal arduino pullup resistors can be used.
    [controller.brd, controller.sch]
2014-10-18 Working on controller board. Simplified scamea a bit.
    [controller.brd, controller.sch]
2014-10-29 Started working on smaller ledboard. Some updates to controll board.
    [controller.sch, lednode3.brd, lednode3.sch]
2014-11-04 Finished lednode v 3.0.
    [lednode3.brd, lednode3.sch]
2014-11-04 Added gerber files for lednode v 3.0.
2014-11-04 Removed generated gerber files. Moved eagle pcb design files to pcb/
    [controller.brd, controller.sch, controlnode.brd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]
2014-11-04 Removed old versions of the lednode and removed version numbers from the filenames.
    [lednode.brd, lednode.sch, lednode2.brd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]
2014-11-04 Removed old node designs.
    [controlnode.brd, controlnode.sch, powernode.brd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]
2014-11-04 Moved different pcbs to different directories.
    [controller.brd, controller.sch, lednode.brd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]
2014-11-04 Work on controller layout.
    [controller.brd, controller.sch]
2014-11-06 Working on remote controller pcb. Added library with connectors and outlines of some of the used third party modules.
    [controller.brd, controller.sch]
2014-11-30 Working on routing.
    [controller.brd, controller.sch]
2014-12-03 Working on lednode software.
2014-12-21 Working on lednode.

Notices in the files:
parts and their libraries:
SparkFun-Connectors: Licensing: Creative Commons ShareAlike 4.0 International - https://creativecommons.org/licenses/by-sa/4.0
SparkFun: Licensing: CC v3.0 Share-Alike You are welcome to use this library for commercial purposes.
